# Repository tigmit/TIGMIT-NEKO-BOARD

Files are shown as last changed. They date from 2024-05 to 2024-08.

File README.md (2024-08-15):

# TIGMIT NEKO BOARD 

HEY fellow nerd :3
thanks for checking out my project hehe

This is a one man project trying to create (my) ultimate keyboard. taylored to the personal needs of a software developer with a thing for cute and weeby shit... hence the name :P 

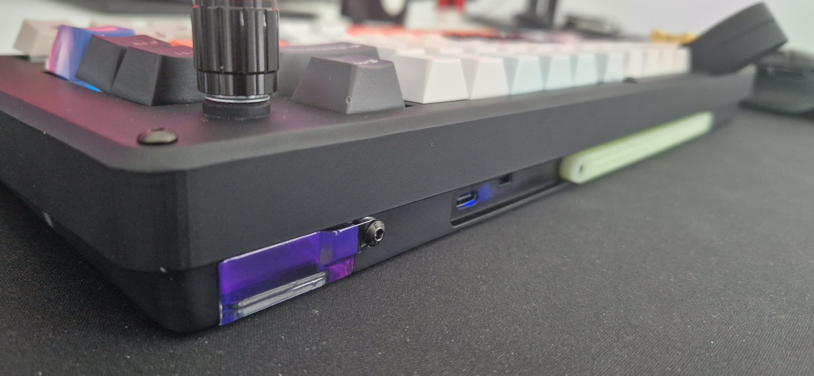
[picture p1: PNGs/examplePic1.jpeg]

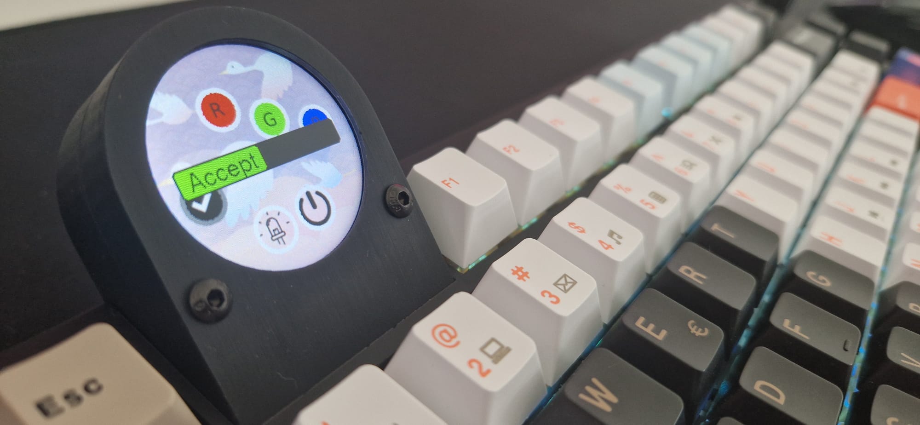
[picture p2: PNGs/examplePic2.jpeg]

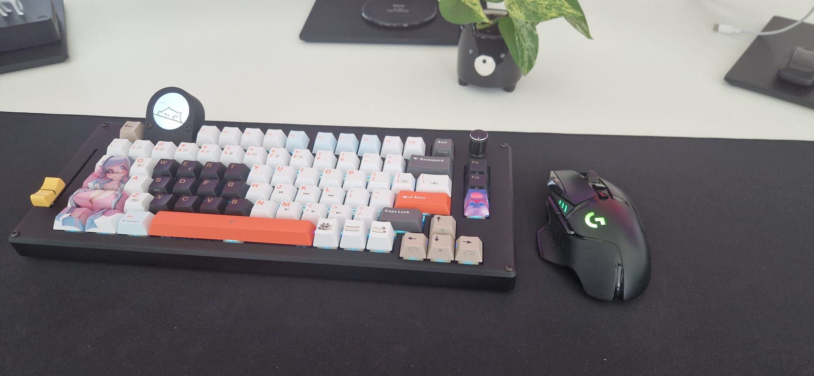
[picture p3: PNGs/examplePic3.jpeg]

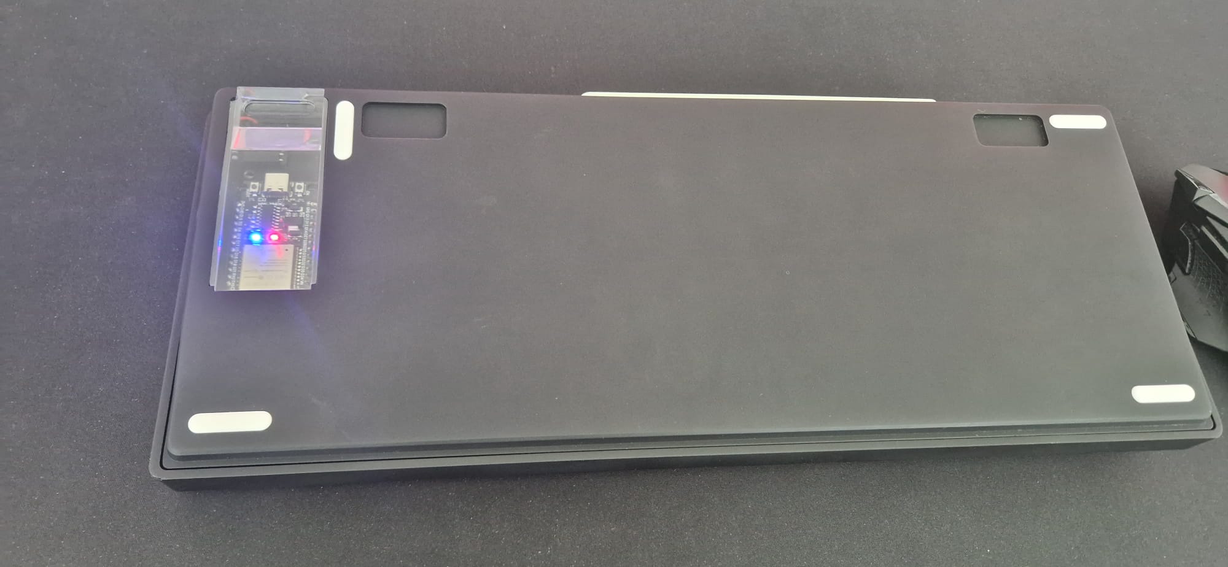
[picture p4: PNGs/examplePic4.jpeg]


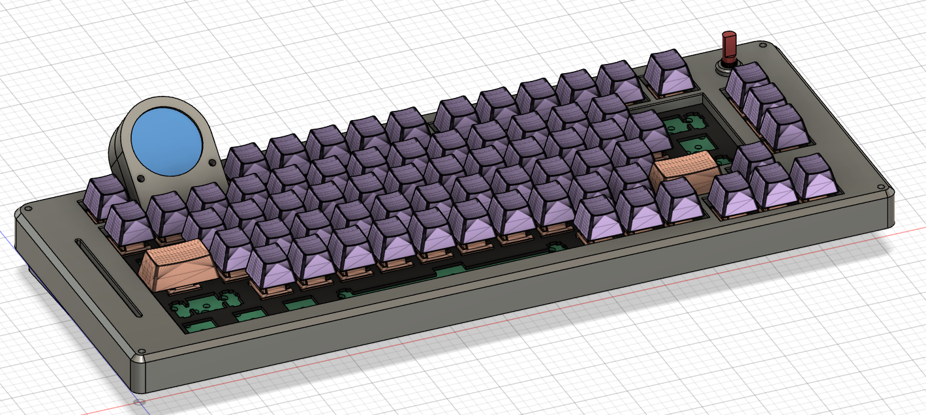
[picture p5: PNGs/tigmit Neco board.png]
TIGMIT NEKO BOARD


the project features 

- 79 keys in a kind of.. compact TKL arrangement.
- a 240 x 240 round Display
- rotary encoder
- analog slider
- fully controllable RGB for each key
- hot swappable switches
- fully custom Firmware (feel free to reuse for your project)
- wireless operation via Bluetooth
- a fully functioal shell with ato completion

to enable the NEKO SHELL go to debugSettings.hpp and enable ```#define DEVMODE ```
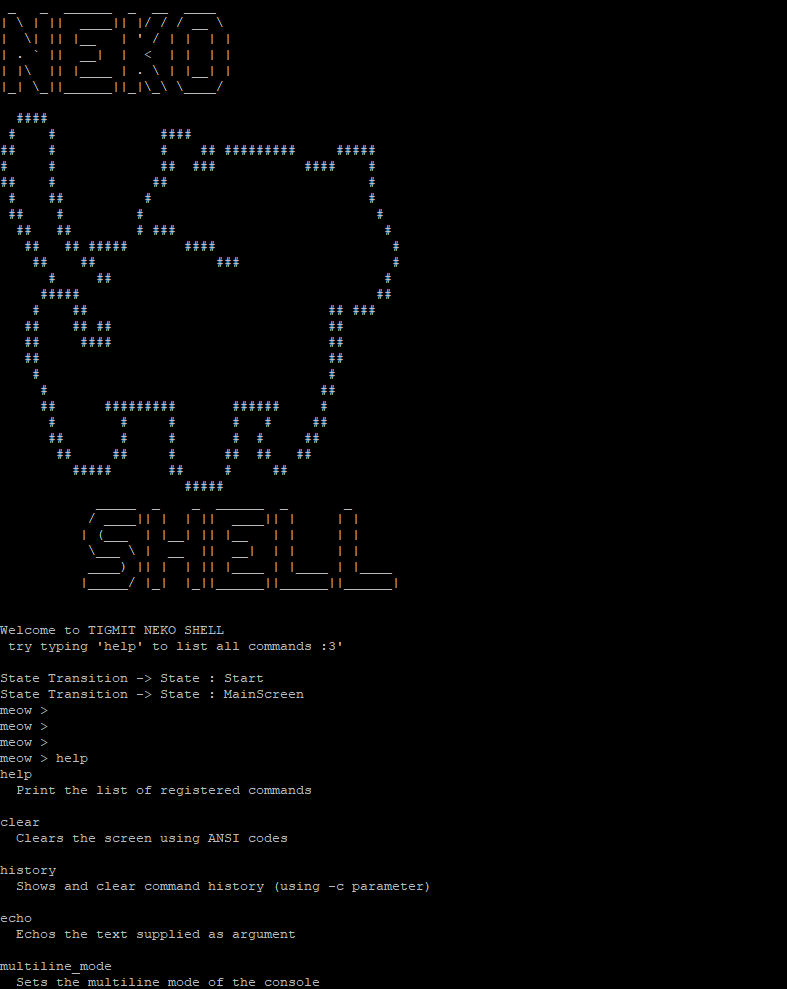
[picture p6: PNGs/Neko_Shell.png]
TIGMIT NEKO BOARD


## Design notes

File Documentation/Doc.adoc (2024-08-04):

# TIGMIT NEKO BOARD 

This is a one man project trying to create (my) ultimate keyboard. taylored to the personal needs of a software developer with a thing for cute and weeby shit... hence the name :P 

image::../PNGs/tigmit Neco board.png[]

the board features 

- 79 keys in a kind of.. compact TKL arrangement.
- a 240 x 240 round Display
- rotary encoder
- analog slider
- fully controllable RGB for each key
- hot swappable 
- the key-plate rests on foam pads to ensure a smoooth typing experience

it's a wireless board using bluetooth to connect to your devices :3

## The brain of the operation

is a esp32 vroom devkit. for now at least. perhaps i will change the controller at some point or integrate it onto the PCB.

anyways it can be accessed for programming via a lid in the bottom of the case as seen here:

image::../PNGs/tigmit Neco board back view.png[]
image::../PNGs/tigmit Neco board bottom view.png[]

it has a fixed angle between 4 and 5 degrees but supprts feet to change the angle to any requred needs really :3

to power the thing it uses a 8000mAh lipo battery with a breakout pcb that handles all of the power tasks like lipo protection and stepping up the battery voltage to 5V for the RGB LEDs

speaking of LEDs. the board has 79 adressable RGB LEDs. more specific SK6812MINI-E (datasheet in Documents/miscFiles Folder)

## KEY Matrix

the keys are arranged as a 6 x 15 Keymatrix. but wait. that uses a total of 21 I/O PINS?! how can we still controll a Display, a slider, and a Rotary encoder with pins to spare?????? well simple hehe the board has TWO 8 bit shift registers wich are controlled via SPI for maximum speeeed. gotta go fast kid.

image::../PNGs/shift registers.png[]

this way its possible to save a massive ammount of pins. reducing the total ammount needed from 21 to basicllay just 8 pins for the whole keymatrix :P 

NOTE: its still very possible to reach a nice 1kHz polling rate for each key so there is no noticable lag when typing because we are utalizing SPI to controll the Shift registers :3

BUT! another trick is needed to pull all of this off with just one ESP32...

### Multicore processing

the esp32 features a delicios dual core MCU which we can use to our advantage hehe

Core 0 runs ONLY the key matrix polling and has priority over all the other tasks. to make absolutely sure that the keyboard... well... TYPES!

Core 1 handles all the other tasks like refreshing the display and running the Display Statemachine with alongside RGB tasks and sooo on. at the expense of a slightly slower refresh rate of the display. but its still fast enough for a nice experience :3 and the display has a buffer itself which eliminates the need to refresh it constantly all together ;P so we only need to update it in when we have to

# USING GC9A01 round TFT Display:

## setup:

### TFT_eSPI Lib

to use the GC9A01 Display, i am using the TFT_eSPI Lib by Bodmer'
https://github.com/Bodmer/TFT_eSPI
it requires some work to set it up for our particular Display.
thats why the TFT_eSPI was moved to the local libs folder in order to make it easyer to clone the repo.

if it does get lost then following changes need to be made in lib\TFT_eSPI\User_Setup.h:

 - select the right Driver. In Line 69 LOL ROFL (/* _ *)/  use #define GC9A01_DRIVER

 - set the requred Pin defines for the Display:

 - you can simply delete everything in the user_setup file and replace it with this setup:

[source,c++]
----
    #define USER_SETUP_INFO "User_Setup"
    #define DISABLE_ALL_LIBRARY_WARNINGS
    #define GC9A01_DRIVER

    #define TFT_MOSI 4  // SDA data signal          (Usr defined)
    #define TFT_SCLK 18 // Clock signal             (must be SCK on your board)
    #define TFT_CS 15   // Chip select control pin  (Usr defined)
    #define TFT_DC 2    // Data Command control pin (Usr defined)
    #define TFT_RST 5   // Reset pin                (Usr defined)

    // Comment out the #defines below with // to stop that font being loaded
    // The ESP8366 and ESP32 have plenty of memory so commenting out fonts is not
    // normally necessary. If all fonts are loaded the extra FLASH space required is
    // about 17Kbytes. To save FLASH space only enable the fonts you need!
    
    #define LOAD_GLCD // Font 1. Original Adafruit 8 pixel font needs ~1820 bytes in
                      // FLASH
    #define LOAD_FONT2 // Font 2. Small 16 pixel high font, needs ~3534 bytes in
                       // FLASH, 96 characters
    #define LOAD_FONT4 // Font 4. Medium 26 pixel high font, needs ~5848 bytes in
                       // FLASH, 96 characters
    #define LOAD_FONT6 // Font 6. Large 48 pixel font, needs ~2666 bytes in FLASH,
                       // only characters 1234567890:-.apm
    #define LOAD_FONT7 // Font 7. 7 segment 48 pixel font, needs ~2438 bytes in
                       // FLASH, only characters 1234567890:-.
    #define LOAD_FONT8 // Font 8. Large 75 pixel font needs ~3256 bytes in FLASH,
                       // only characters 1234567890:-.
    //#define LOAD_FONT8N // Font 8. Alternative to Font 8 above, slightly narrower,
    // so 3 digits fit a 160 pixel TFT
    #define LOAD_GFXFF // FreeFonts. Include access to the 48 Adafruit_GFX free
                       // fonts FF1 to FF48 and custom fonts
    
    // Comment out the #define below to stop the SPIFFS filing system and smooth
    // font code being loaded this will save ~20kbytes of FLASH
    #define SMOOTH_FONT
    
    // #define SPI_FREQUENCY   1000000
    // #define SPI_FREQUENCY   5000000
    // #define SPI_FREQUENCY  10000000
    // #define SPI_FREQUENCY  20000000
    #define SPI_FREQUENCY 27000000
    // #define SPI_FREQUENCY  40000000
    // #define SPI_FREQUENCY  55000000 // STM32 SPI1 only (SPI2 maximum is 27MHz)
    // #define SPI_FREQUENCY  80000000
    
    // Optional reduced SPI frequency for reading TFT
    #define SPI_READ_FREQUENCY 20000000
    
    // The XPT2046 requires a lower SPI clock rate of 2.5MHz so we define that here:
    #define SPI_TOUCH_FREQUENCY 2500000
----

connect these pins as per the defines and you should be good to go.

# NEKO SHELL

The project features a fully functional live console/Shell to debug and play around.

find more info on how to create your own commands inside ```NekoShell.hpp```

To enable the NEKO SHELL go to debugSettings.hpp and enable ```#define DEVMODE```



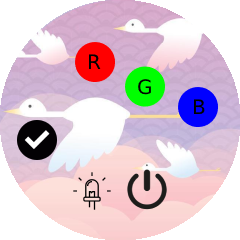
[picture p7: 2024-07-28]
PNGs/DSPwallpapers/LED_Settings_Screen.png

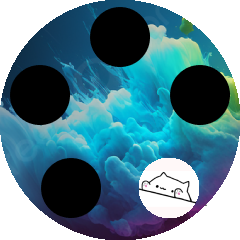
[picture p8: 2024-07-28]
PNGs/DSPwallpapers/main_menu_screen1.png

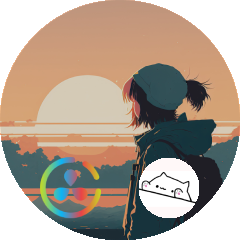
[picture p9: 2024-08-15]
PNGs/DSPwallpapers/main_menu_screen.png

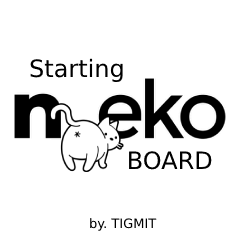
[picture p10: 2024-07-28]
PNGs/DSPwallpapers/start screen with name.png

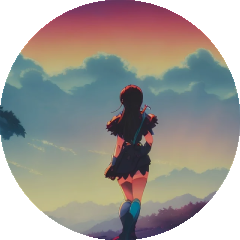
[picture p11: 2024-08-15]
PNGs/DSPwallpapers/idleScreen.png

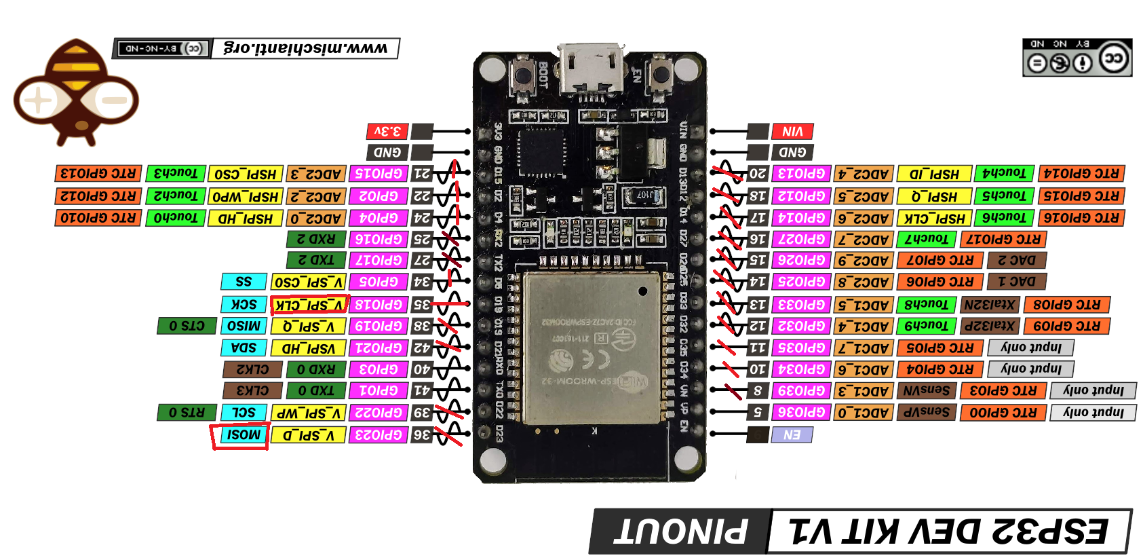
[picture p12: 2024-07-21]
Documentation/miscFiles/ESP32-DOIT-DEV-KIT-v1-pinout-mischianti.png

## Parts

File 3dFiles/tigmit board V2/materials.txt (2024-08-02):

bottom main case:
SLA Resin -> imagine black

display front plate:
SLA Resin -> imagine black

Display mount block:
SLA Resin -> imagine black

Lid Main case:
SLA Resin -> imagine black

MCU access lid:
SLA Resin -> 8001 Resin transparent

Keyplate:
SLA Resin -> 8001 Resin Translucent

beauty rail:
SLA Resin -> X Resin

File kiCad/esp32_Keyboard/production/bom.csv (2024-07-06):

Designator | Footprint | Quantity | Value | LCSC Part #
C1, C2 | CP_Elec_6.3x5.2 | 2 | 100µF
D1, D10, D11, D12, D13, D14, D15, D16, D17, D18, D19, D2, D20, D21, D22, D23, D24, D25, D26, D27, D28, D29, D3, D30, D31, D32, D33, D34, D35, D36, D37, D38, D39, D4, D40, D41, D42, D43, D44, D45, D46, D47, D48, D49, D5, D50, D51, D52, D53, D54, D55, D56, D57, D58, D59, D6, D60, D61, D62, D63, D64, D65, D66, D67, D68, D69, D7, D70, D71, D72, D73, D74, D75, D76, D77, D78, D79, D8, D9 | Diode_SOD-123 | 79 | Diode
Dsp1 | PinHeader_1x07_P2.54mm_Vertical | 1 | ~
PWR_Module1 | PinHeader_1x04_P2.54mm_Vertical | 1 | Conn_01x04_Pin
R1, R2, R3, R4, R5, R6, R7 | R_Axial_DIN0204_L3.6mm_D1.6mm_P7.62mm_Horizontal | 7 | 10k
RotaryEnc1 | PinHeader_1x05_P2.54mm_Vertical | 1 | Conn_01x05_Pin
S1, S2, S3 | STAB_MX_2u | 3 | stab 2u
S4 | STAB_MX_6.25u | 1 | stab space 6.25u
SW1, SW10, SW11, SW12, SW13, SW14, SW15, SW16, SW17, SW18, SW19, SW2, SW20, SW21, SW22, SW23, SW24, SW25, SW26, SW27, SW28, SW29, SW3, SW30, SW31, SW32, SW33, SW34, SW35, SW36, SW37, SW38, SW39, SW4, SW40, SW41, SW42, SW43, SW44, SW45, SW46, SW47, SW48, SW49, SW5, SW50, SW51, SW52, SW53, SW54, SW55, SW56, SW57, SW58, SW59, SW6, SW60, SW61, SW62, SW63, SW64, SW65, SW66, SW67, SW68, SW69, SW7, SW70, SW71, SW72, SW73, SW74, SW75, SW76, SW77, SW78, SW79, SW8, SW9 | hotswap socket with neopixel | 79 | ~
U1 | SNH Shift register | 1 | SN74HC595NG4 FirstShift
U2 | SNH Shift register | 1 | SN74HC595NG4 SecondShift
U3 | CONV_BOB-12009 | 1 | BOB-12009
U4 | b103 multichannel fader pot | 1 | ~
U5 | ESP32 Vroom Devkit V1 | 1 | ESP32-DEVKIT-V1 Matrix Handler

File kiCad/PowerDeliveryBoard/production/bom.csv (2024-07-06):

Designator | Footprint | Quantity | Value | LCSC Part #
BT1 | battery solder pins | 1 | Battery_Cell
C1 | CP_Elec_6.3x5.2 | 1 | 100µF
DCDC1 | DCDC-Converter | 1 | ~
J1 | PinHeader_1x04_P2.54mm_Vertical | 1 | Conn_01x04_Pin
R1 | R_Axial_DIN0204_L3.6mm_D1.6mm_P7.62mm_Horizontal | 1 | 4k7
R2 | R_Axial_DIN0204_L3.6mm_D1.6mm_P7.62mm_Horizontal | 1 | 10k
R3, R4 | R_Axial_DIN0204_L3.6mm_D1.6mm_P7.62mm_Horizontal | 2 | 100k
U1 | TP4056-18650 | 1 | ~
U2 | SK12D07VG4 | 1 | SK12D07VG4

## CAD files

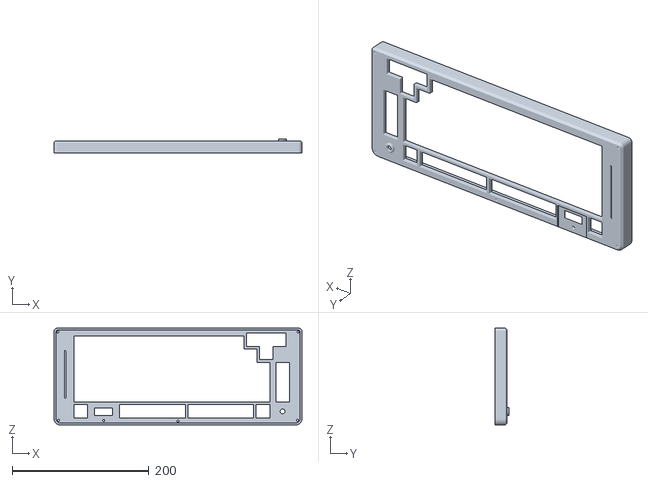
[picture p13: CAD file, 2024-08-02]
3dFiles/tigmit board V2/Lid Main case.stl
362.9 x 21.1 x 141.8

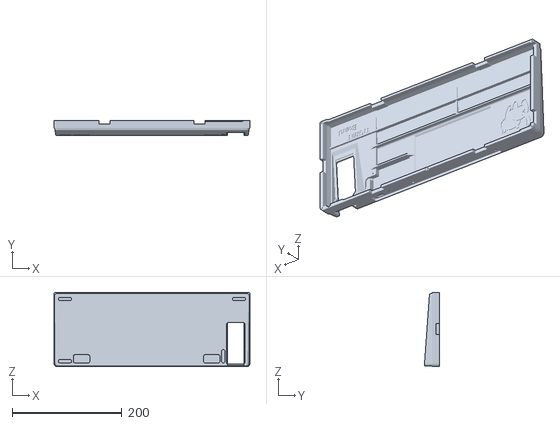
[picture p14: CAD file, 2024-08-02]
3dFiles/tigmit board V2/bottom Main case.stl
356.5 x 27.9 x 135.4

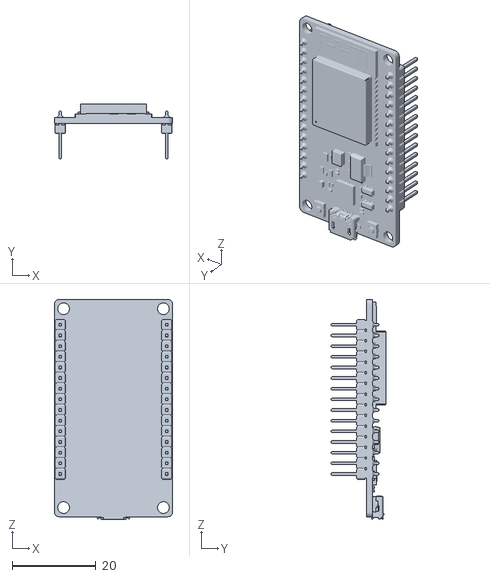
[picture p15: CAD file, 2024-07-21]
3dFiles/ESP32-DEVKIT-V1--3DModel.stl
28.2 x 13.1 x 52.4

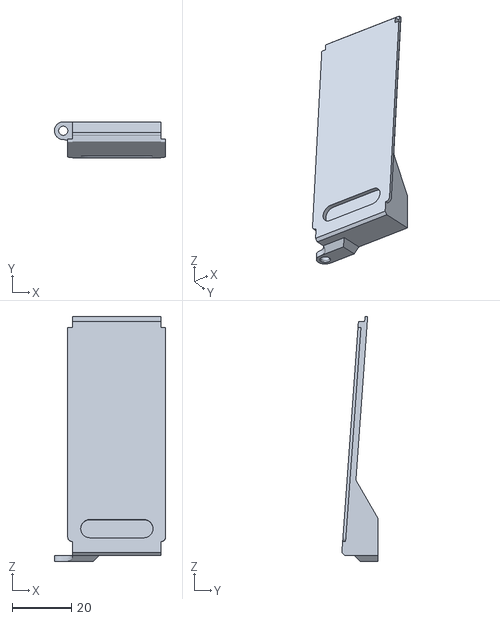
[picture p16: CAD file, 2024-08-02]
3dFiles/tigmit board V2/MCU access Lid_.stl
37.5 x 12.2 x 82.6

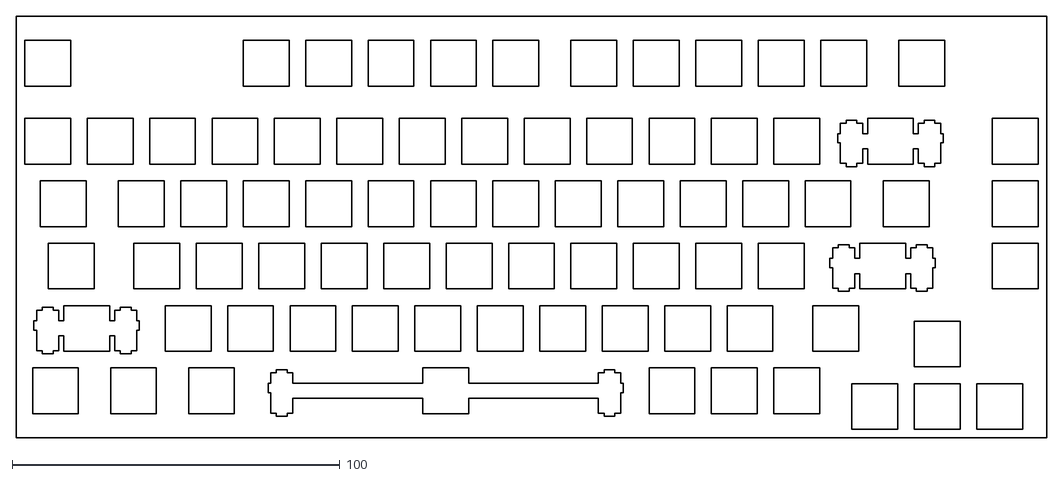
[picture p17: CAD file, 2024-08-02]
Documentation/miscFiles/TKL_Cherry_Only_Keyplate.dxf
314.3 x 128.6

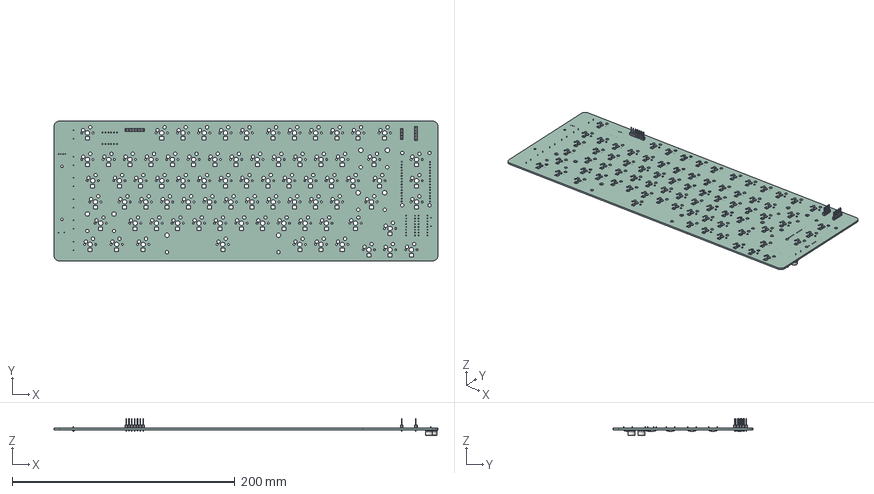
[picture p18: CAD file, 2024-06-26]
kiCad/esp32_Keyboard/esp32_Keyboard.step
344.5 x 125.4 x 15.4 mm
PinHeader_1x05_P254mm_Vertical
PinHeader_1x04_P254mm_Vertical
PinHeader_1x07_P254mm_Vertical
CP_Elec_63x52 x 2
R_Axial_DIN0204_L36mm_D16mm_P762mm_Horizontal x 7
_autosave-esp32_Keyboard_PCB

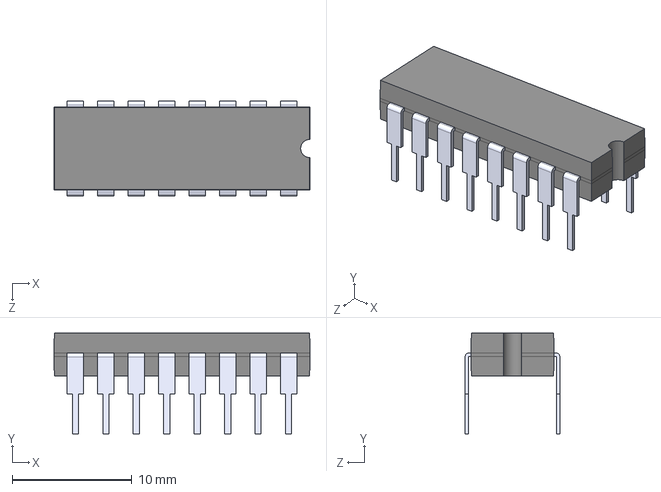
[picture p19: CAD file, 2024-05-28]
kiCad/parts/SN74HC595NG4/SN74HC595NG4.step
21.3 x 8.38 x 7.90 mm

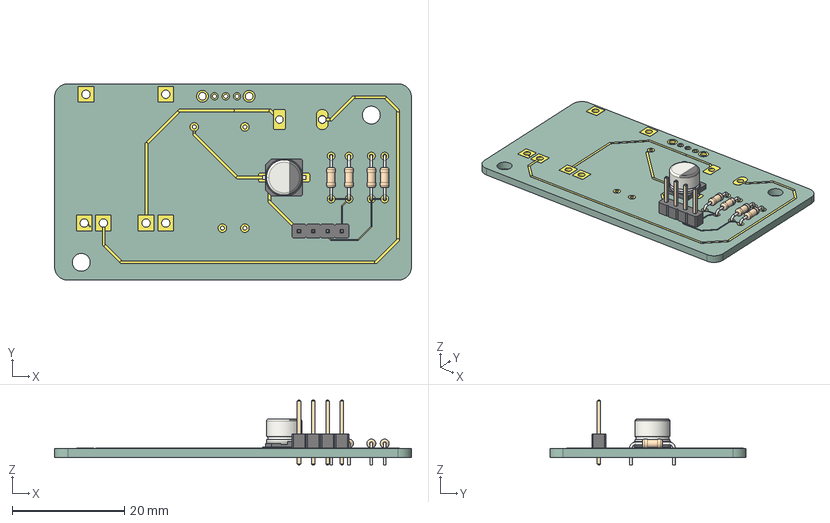
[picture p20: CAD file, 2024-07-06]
kiCad/PowerDeliveryBoard/PowerDeliveryBoard.step
63.5 x 34.9 x 11.5 mm
R_Axial_DIN0204_L36mm_D16mm_P762mm_Horizontal x 4
PinHeader_1x04_P254mm_Vertical
CP_Elec_63x52
PowerDeliveryBoard_track_1
PowerDeliveryBoard_track_2
PowerDeliveryBoard_track_3
PowerDeliveryBoard_track_4
PowerDeliveryBoard_track_5
PowerDeliveryBoard_track_6
PowerDeliveryBoard_track_7
PowerDeliveryBoard_track_8
PowerDeliveryBoard_track_9
PowerDeliveryBoard_track_10
PowerDeliveryBoard_track_11
PowerDeliveryBoard_track_12
PowerDeliveryBoard_track_13
PowerDeliveryBoard_track_14
PowerDeliveryBoard_track_15
PowerDeliveryBoard_track_16
PowerDeliveryBoard_track_17
PowerDeliveryBoard_track_18
PowerDeliveryBoard_track_19
PowerDeliveryBoard_track_20
PowerDeliveryBoard_track_21
PowerDeliveryBoard_track_22
PowerDeliveryBoard_track_23
PowerDeliveryBoard_track_24
PowerDeliveryBoard_track_25
PowerDeliveryBoard_track_26
PowerDeliveryBoard_track_27
PowerDeliveryBoard_track_28
PowerDeliveryBoard_track_29
PowerDeliveryBoard_track_30
PowerDeliveryBoard_track_31
PowerDeliveryBoard_track_32
PowerDeliveryBoard_track_33
PowerDeliveryBoard_track_34
PowerDeliveryBoard_track_35
PowerDeliveryBoard_track_36
PowerDeliveryBoard_track_37
PowerDeliveryBoard_track_38
PowerDeliveryBoard_track_39
PowerDeliveryBoard_track_40
PowerDeliveryBoard_track_41
PowerDeliveryBoard_track_42
PowerDeliveryBoard_track_43
PowerDeliveryBoard_track_44
PowerDeliveryBoard_track_45
PowerDeliveryBoard_track_46
PowerDeliveryBoard_track_47
PowerDeliveryBoard_track_48
PowerDeliveryBoard_track_49
PowerDeliveryBoard_track_50
PowerDeliveryBoard_pad_1
PowerDeliveryBoard_pad_2
PowerDeliveryBoard_pad_3
PowerDeliveryBoard_pad_4
PowerDeliveryBoard_pad_5
PowerDeliveryBoard_pad_6
PowerDeliveryBoard_pad_7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

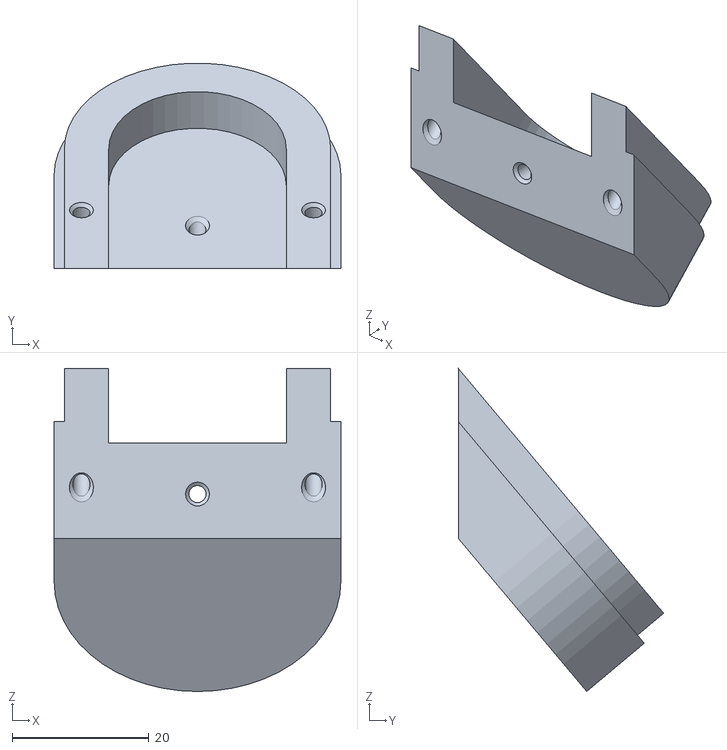
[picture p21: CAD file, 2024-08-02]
3dFiles/tigmit board V2/Display mount block.stl
42.0 x 30.1 x 47.3

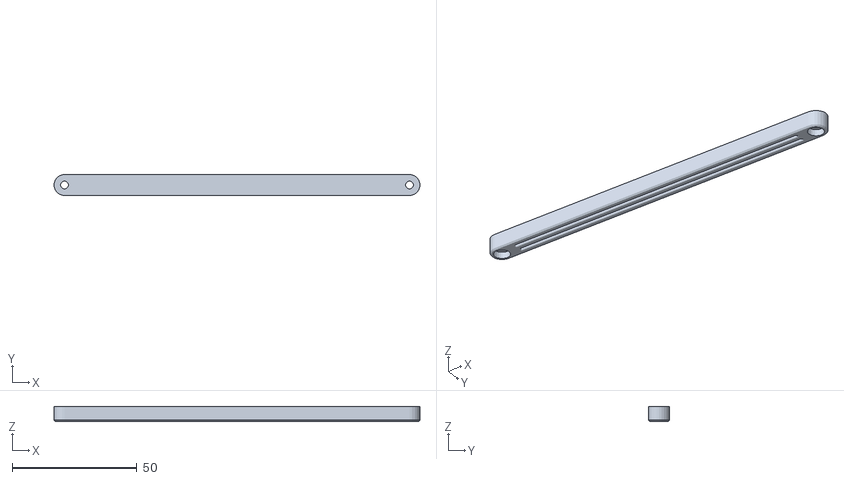
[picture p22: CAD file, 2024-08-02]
3dFiles/tigmit board V2/beauty rail.stl
146.5 x 8.40 x 6.00

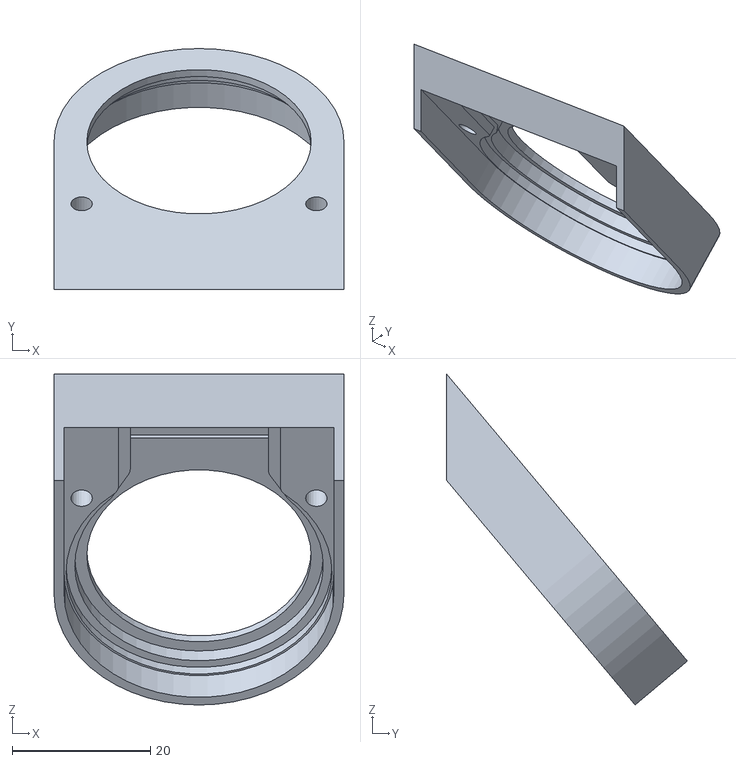
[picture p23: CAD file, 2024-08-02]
3dFiles/tigmit board V2/display front Plate.stl
42.0 x 34.9 x 47.9

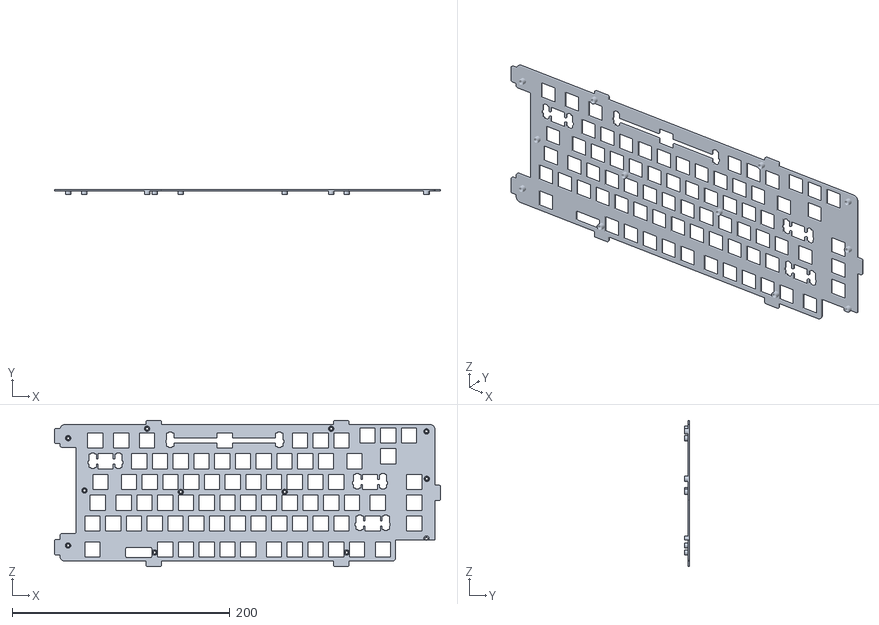
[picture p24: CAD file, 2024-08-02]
3dFiles/tigmit board V2/keyplate MX only pcb mount stabs.stl
354.5 x 5.00 x 134.1

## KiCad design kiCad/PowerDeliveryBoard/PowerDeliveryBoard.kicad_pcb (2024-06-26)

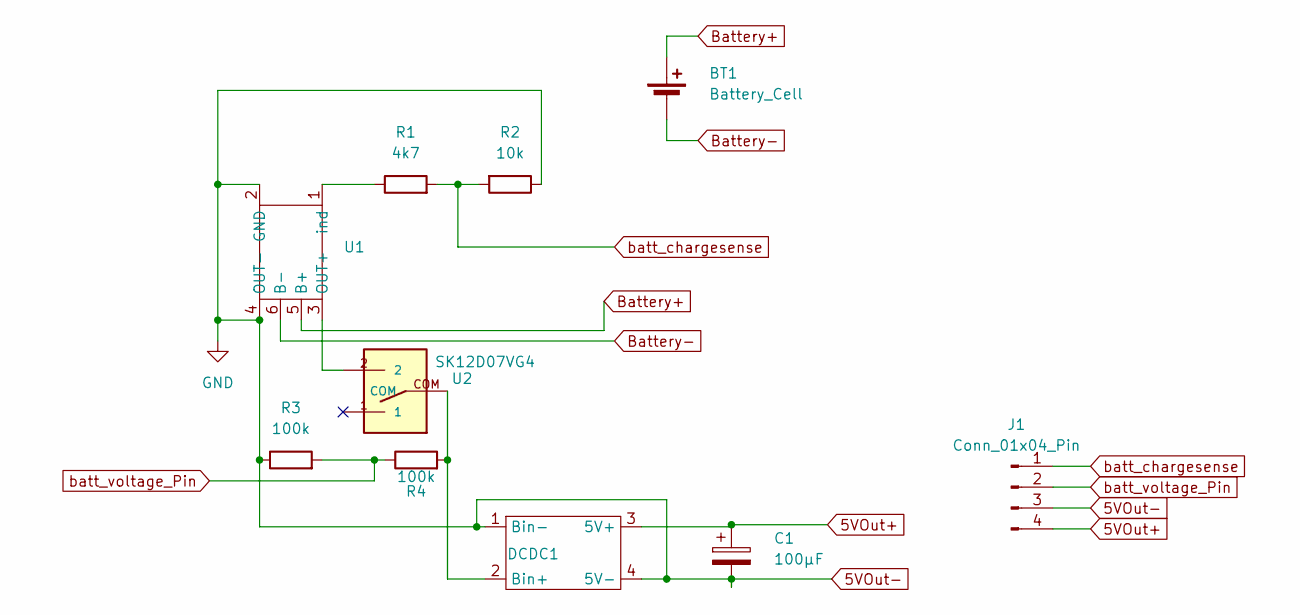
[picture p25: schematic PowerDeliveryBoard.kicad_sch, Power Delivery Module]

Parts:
BT1: Battery_Cell; battery solder pins
C1: 100µF; CP_Elec_6.3x5.2
DCDC1: DCDC-Converter
J1: Conn_01x04_Pin; PinHeader_1x04_P2.54mm_Vertical
R1: 4k7; R_Axial_DIN0204_L3.6mm_D1.6mm_P7.62mm_Horizontal
R2: 10k; R_Axial_DIN0204_L3.6mm_D1.6mm_P7.62mm_Horizontal
R3, R4: 100k; R_Axial_DIN0204_L3.6mm_D1.6mm_P7.62mm_Horizontal
U1: TP4056-18650
U2: SK12D07VG4

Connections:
5VOut+: C1.1, DCDC1.3 (5V+), J1.4
5VOut-: C1.2, DCDC1.1 (Bin-), DCDC1.4 (5V-), J1.3, R2.1, R3.1, U1.2 (GND), U1.4 (OUT-)
Battery+: BT1.1 (+), U1.5 (B+)
Battery-: BT1.2 (-), U1.6 (B-)
unnamed: DCDC1.2 (Bin+), R4.2, U2.COM
unnamed: U1.3 (OUT+), U2.2
unnamed: R1.1, U1.1 (ind)
batt_chargesense: J1.1, R1.2, R2.2
batt_voltage_Pin: J1.2, R3.2, R4.1

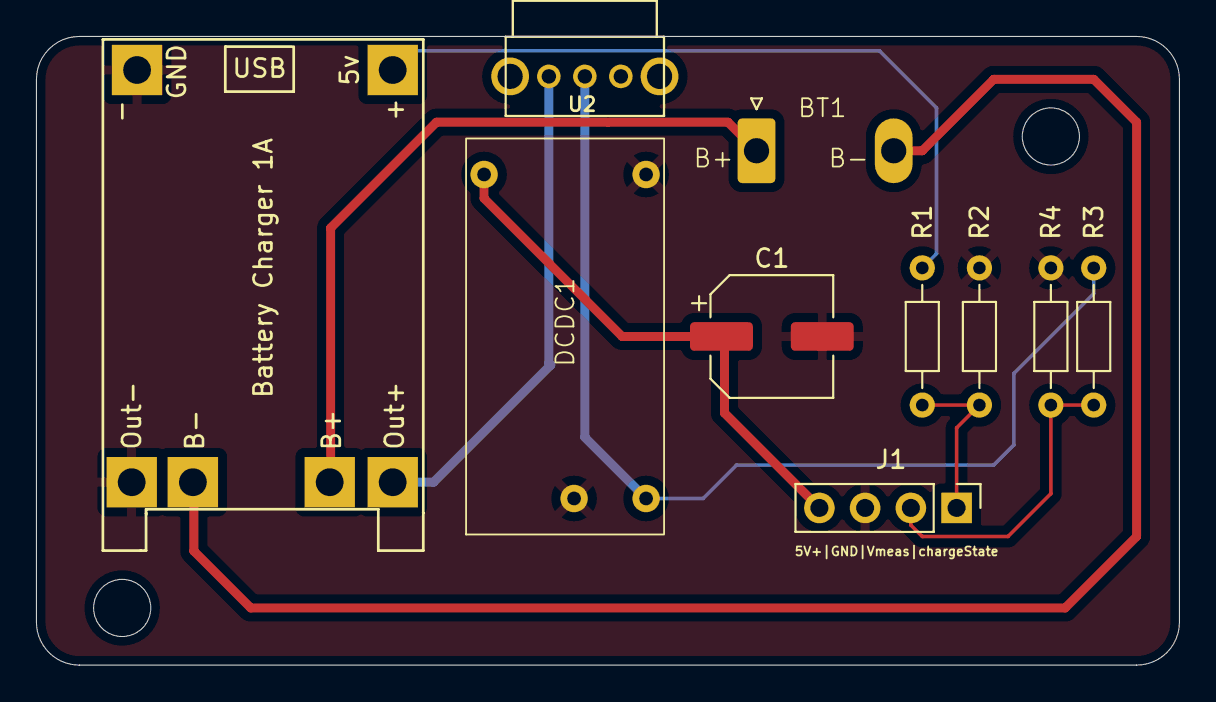
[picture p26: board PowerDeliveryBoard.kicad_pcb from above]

Board: 2 copper layers, 63.5 x 34.9 mm, 10 parts (0 on the bottom side), 9 nets.

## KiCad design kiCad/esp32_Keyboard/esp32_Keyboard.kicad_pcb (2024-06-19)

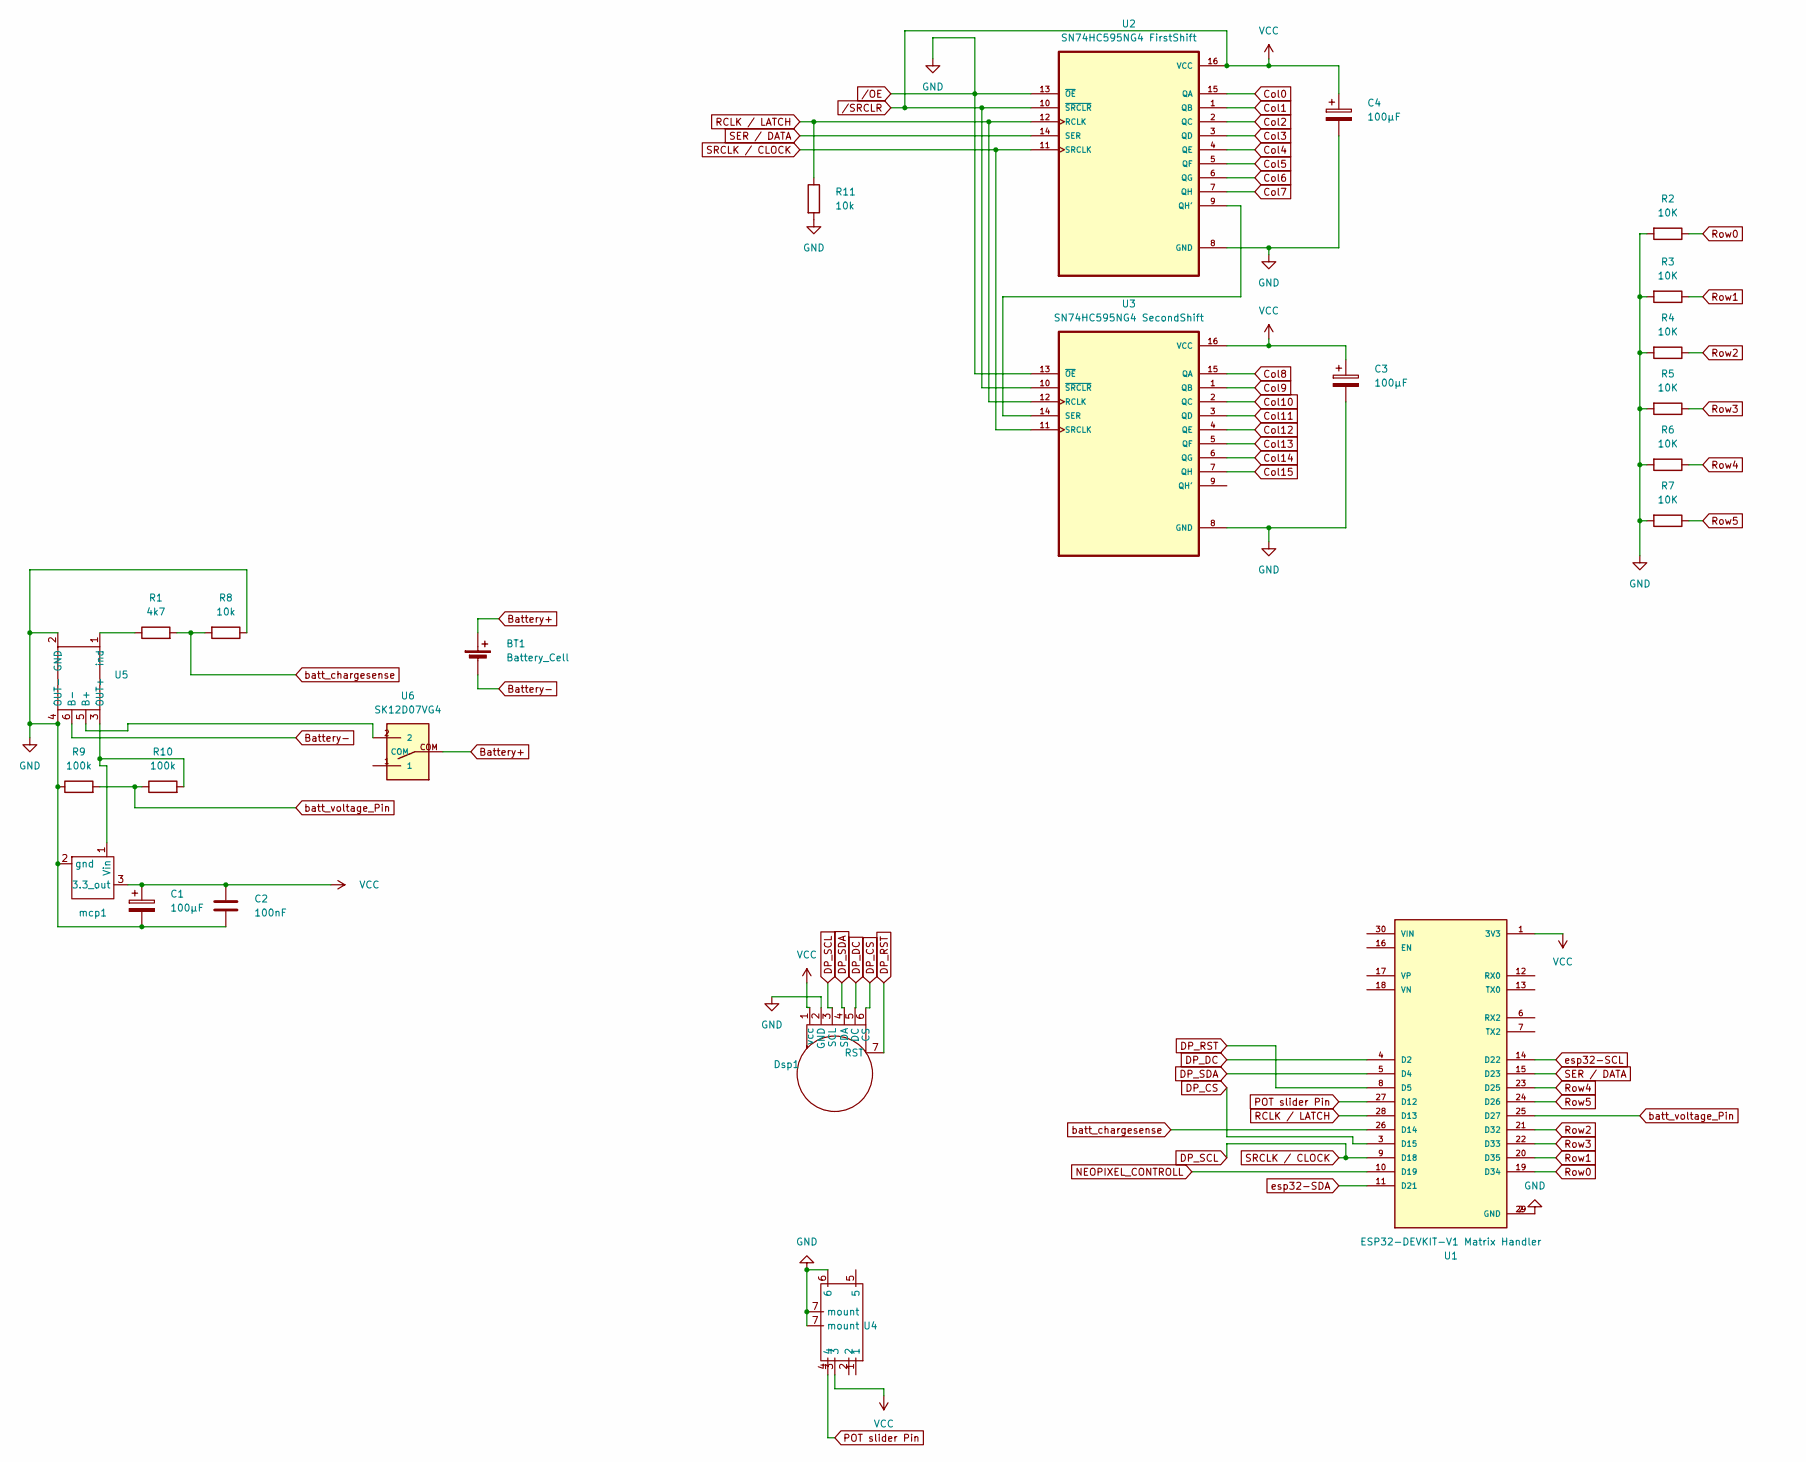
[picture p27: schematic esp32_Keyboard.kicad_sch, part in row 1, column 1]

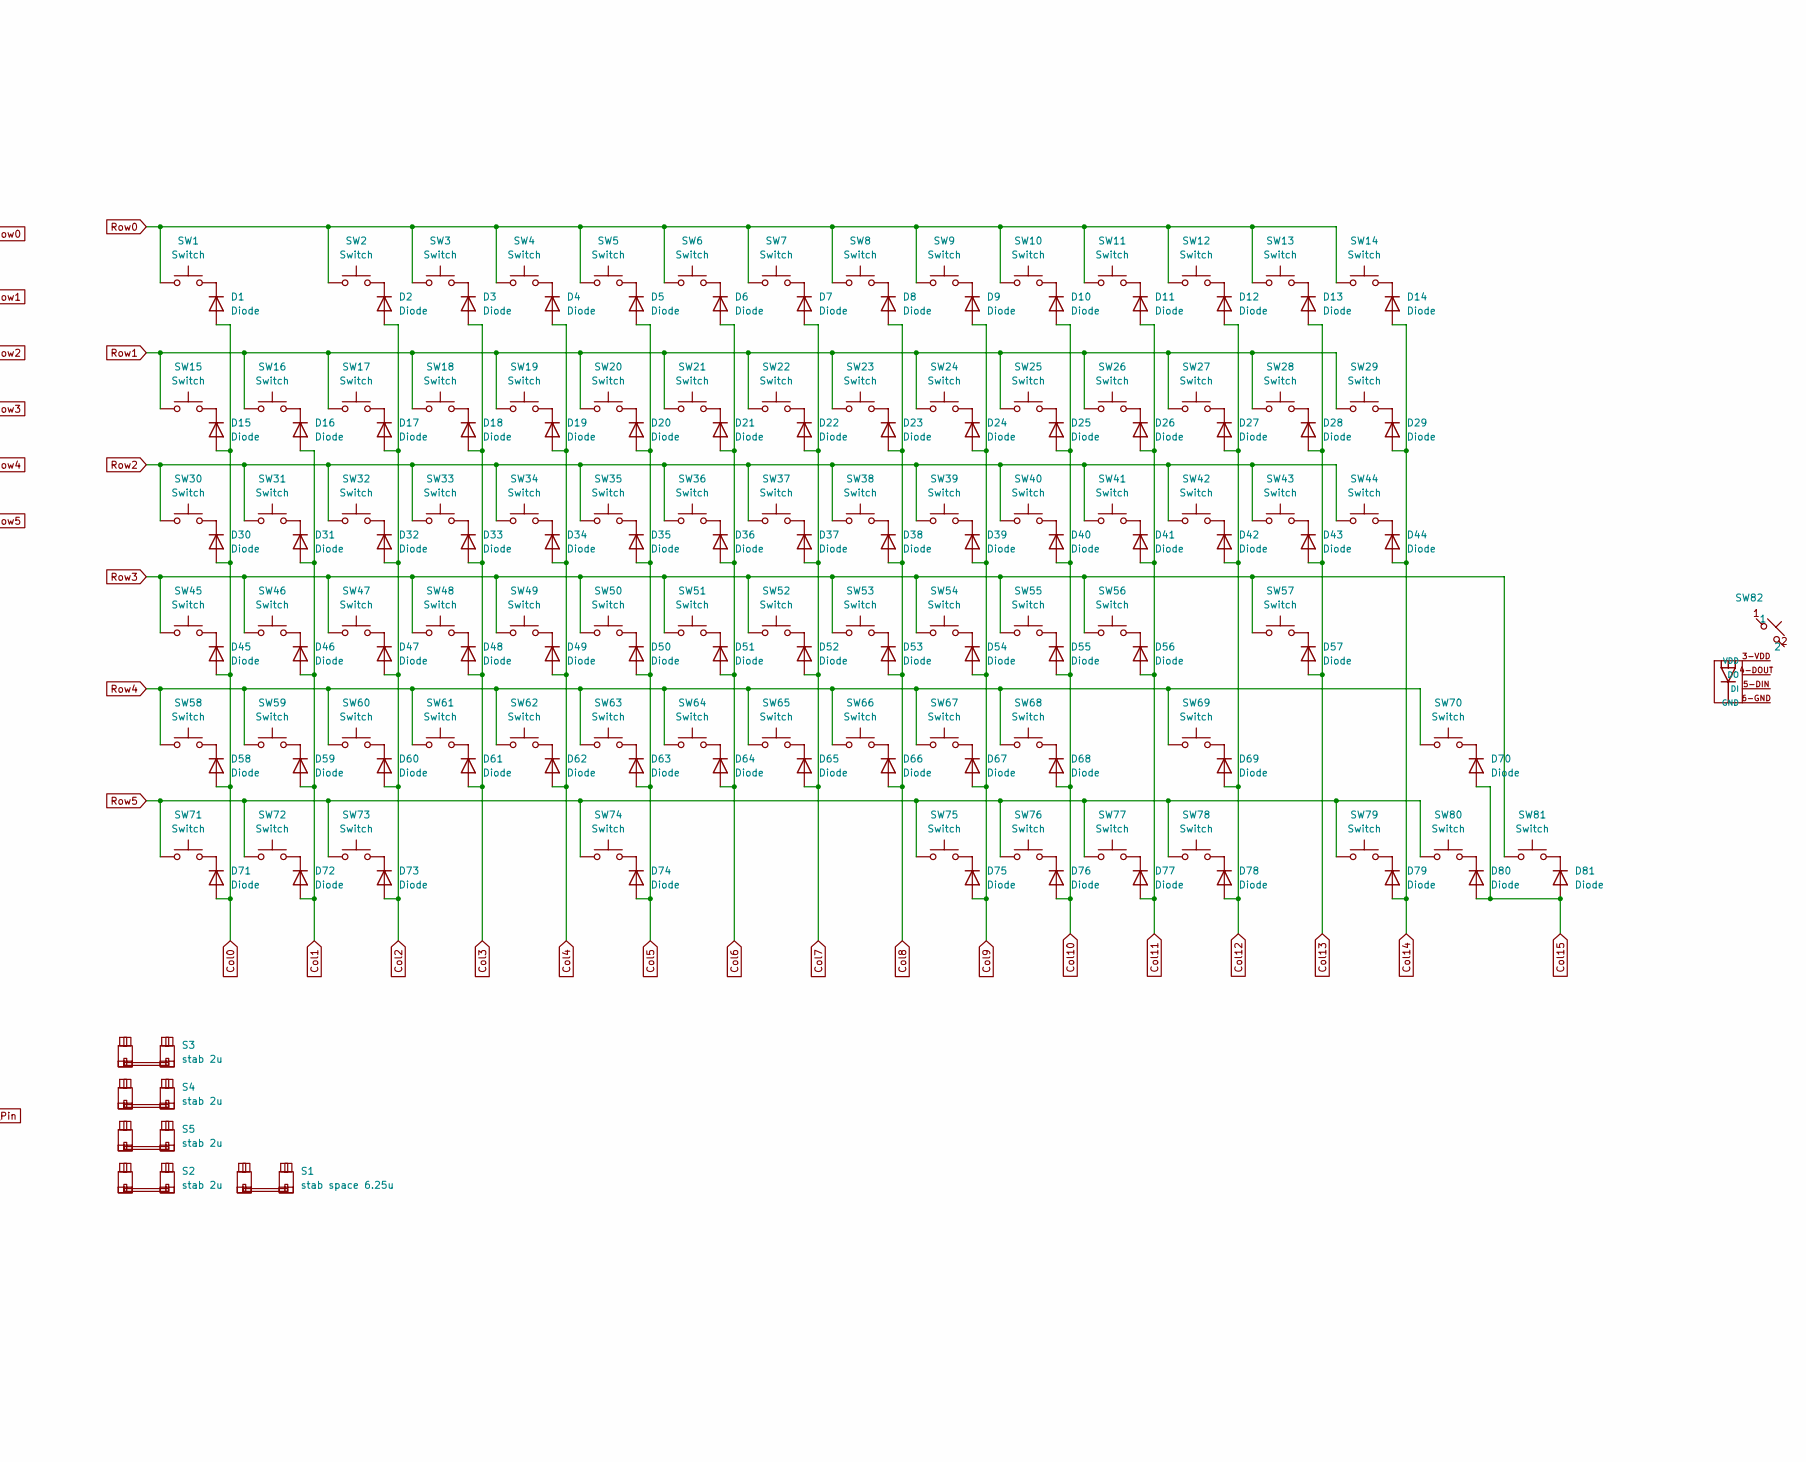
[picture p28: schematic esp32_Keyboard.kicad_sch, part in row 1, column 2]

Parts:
BT1: Battery_Cell; battery solder pins
C1, C3, C4: 100µF; CP_Radial_D10.0mm_P2.50mm
C2: 100nF; C_Rect_L7.0mm_W2.5mm_P5.00mm
D1, D2, D3, D4, D5, D6, D7, D8, D9, D10, D11, D12, D13, D14, D15, D16, D17, D18, D19, D20, D21, D22, D23, D24, D25, D26, D27, D28, D29, D30, D31, D32, D33, D34, D35, D36, D37, D38, D39, D40, D41, D42, D43, D44, D45, D46, D47, D48, D49, D50, D51, D52, D53, D54, D55, D56, D57, D58, D59, D60, D61, D62, D63, D64, D65, D66, D67, D68, D69, D70, D71, D72, D73, D74, D75, D76, D77, D78, D79, D80, D81: Diode; Diode_SOD-123
Dsp1: PinHeader_1x07_P2.54mm_Vertical
R1: 4k7; R_Axial_DIN0204_L3.6mm_D1.6mm_P7.62mm_Horizontal
R2, R3, R4, R5, R6, R7: 10K; R_Axial_DIN0204_L3.6mm_D1.6mm_P7.62mm_Horizontal
R8, R11: 10k; R_Axial_DIN0204_L3.6mm_D1.6mm_P7.62mm_Horizontal
R9, R10: 100k; R_Axial_DIN0204_L3.6mm_D1.6mm_P7.62mm_Horizontal
S1: stab space 6.25u; STAB_MX_6.25u
S2, S3, S4, S5: stab 2u; STAB_MX_2u
SW1, SW2, SW3, SW4, SW5, SW6, SW7, SW8, SW9, SW10, SW11, SW12, SW13, SW14, SW15, SW16, SW17, SW18, SW19, SW20, SW21, SW22, SW23, SW24, SW25, SW26, SW27, SW29, SW31, SW32, SW33, SW34, SW35, SW36, SW37, SW38, SW39, SW40, SW41, SW42, SW44, SW46, SW47, SW48, SW49, SW50, SW51, SW52, SW53, SW54, SW55, SW56, SW59, SW60, SW61, SW62, SW63, SW64, SW65, SW66, SW67, SW68, SW70, SW79, SW80, SW81: Switch; Hotswap_MX_1.00u
SW28: Switch; Hotswap_MX_2.00u
SW30, SW43: Switch; Hotswap_MX_1.50u
SW45: Switch; Hotswap_MX_1.75u
SW57, SW58: Switch; Hotswap_MX_2.25u
SW69: Switch; Hotswap_MX_2.75u
SW71, SW72, SW73, SW75, SW76, SW77, SW78: Switch; Hotswap_MX_1.25u
SW74: Switch; Hotswap_MX_6.25u
SW82: hotswap socket with neopixel
U1: ESP32-DEVKIT-V1 Matrix Handler; ESP32 Vroom Devkit V1; PARTREV N/A
U2: SN74HC595NG4 FirstShift; SNH Shift register
U3: SN74HC595NG4 SecondShift; SNH Shift register
U4: b103 multichannel fader pot
U5: TP4056-18650
U6: SK12D07VG4
mcp1: MCP1700 3.3V

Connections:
Battery+: BT1.1 (+), U6.COM
Battery-: BT1.2 (-), U5.6 (B-)
Col0: D1.2 (A), D15.2 (A), D30.2 (A), D45.2 (A), D58.2 (A), D71.2 (A), U2.15 (QA)
Col1: D16.2 (A), D31.2 (A), D46.2 (A), D59.2 (A), D72.2 (A), U2.1 (QB)
Col2: D2.2 (A), D17.2 (A), D32.2 (A), D47.2 (A), D60.2 (A), D73.2 (A), U2.2 (QC)
Col3: D3.2 (A), D18.2 (A), D33.2 (A), D48.2 (A), D61.2 (A), U2.3 (QD)
Col4: D4.2 (A), D19.2 (A), D34.2 (A), D49.2 (A), D62.2 (A), U2.4 (QE)
Col5: D5.2 (A), D20.2 (A), D35.2 (A), D50.2 (A), D63.2 (A), D74.2 (A), U2.5 (QF)
Col6: D6.2 (A), D21.2 (A), D36.2 (A), D51.2 (A), D64.2 (A), U2.6 (QG)
Col7: D7.2 (A), D22.2 (A), D37.2 (A), D52.2 (A), D65.2 (A), U2.7 (QH)
Col8: D8.2 (A), D23.2 (A), D38.2 (A), D53.2 (A), D66.2 (A), U3.15 (QA)
Col9: D9.2 (A), D24.2 (A), D39.2 (A), D54.2 (A), D67.2 (A), D75.2 (A), U3.1 (QB)
Col10: D10.2 (A), D25.2 (A), D40.2 (A), D55.2 (A), D68.2 (A), D76.2 (A), U3.2 (QC)
Col11: D11.2 (A), D26.2 (A), D41.2 (A), D56.2 (A), D77.2 (A), U3.3 (QD)
Col12: D12.2 (A), D27.2 (A), D42.2 (A), D69.2 (A), D78.2 (A), U3.4 (QE)
Col13: D13.2 (A), D28.2 (A), D43.2 (A), D57.2 (A), U3.5 (QF)
Col14: D14.2 (A), D29.2 (A), D44.2 (A), D79.2 (A), U3.6 (QG)
Col15: D70.2 (A), D80.2 (A), D81.2 (A), U3.7 (QH)
DP_CS: Dsp1.6 (CS), U1.3 (D15)
DP_DC: Dsp1.5 (DC), U1.4 (D2)
DP_RST: Dsp1.7 (RST), U1.8 (D5)
DP_SCL: Dsp1.3 (SCL), U1.9 (D18), U2.11 (SRCLK), U3.11 (SRCLK)
DP_SDA: Dsp1.4 (SDA), U1.5 (D4)
NEOPIXEL_CONTROLL: U1.10 (D19)
unnamed: D1.1 (K), SW1.2
unnamed: D2.1 (K), SW2.2
unnamed: D3.1 (K), SW3.2
unnamed: D4.1 (K), SW4.2
unnamed: D5.1 (K), SW5.2
unnamed: D6.1 (K), SW6.2
unnamed: D7.1 (K), SW7.2
unnamed: D8.1 (K), SW8.2
unnamed: D9.1 (K), SW9.2
unnamed: D10.1 (K), SW10.2
unnamed: D11.1 (K), SW11.2
unnamed: D12.1 (K), SW12.2
unnamed: D13.1 (K), SW13.2
unnamed: D14.1 (K), SW14.2
unnamed: D15.1 (K), SW15.2
unnamed: D16.1 (K), SW16.2
unnamed: D17.1 (K), SW17.2
unnamed: D18.1 (K), SW18.2
unnamed: D19.1 (K), SW19.2
unnamed: D20.1 (K), SW20.2
unnamed: D21.1 (K), SW21.2
unnamed: D22.1 (K), SW22.2
unnamed: D23.1 (K), SW23.2
unnamed: D24.1 (K), SW24.2
unnamed: D25.1 (K), SW25.2
unnamed: D26.1 (K), SW26.2
unnamed: D27.1 (K), SW27.2
unnamed: D28.1 (K), SW28.2
unnamed: D29.1 (K), SW29.2
unnamed: D30.1 (K), SW30.2
unnamed: D31.1 (K), SW31.2
unnamed: D32.1 (K), SW32.2
unnamed: D33.1 (K), SW33.2
unnamed: D34.1 (K), SW34.2
unnamed: D35.1 (K), SW35.2
unnamed: D36.1 (K), SW36.2
unnamed: D37.1 (K), SW37.2
unnamed: D38.1 (K), SW38.2
unnamed: D39.1 (K), SW39.2
unnamed: D40.1 (K), SW40.2
unnamed: D41.1 (K), SW41.2
unnamed: D42.1 (K), SW42.2
unnamed: D43.1 (K), SW43.2
unnamed: D44.1 (K), SW44.2
unnamed: D45.1 (K), SW45.2
unnamed: D46.1 (K), SW46.2
unnamed: D47.1 (K), SW47.2
unnamed: D48.1 (K), SW48.2
unnamed: D49.1 (K), SW49.2
unnamed: D50.1 (K), SW50.2
unnamed: D51.1 (K), SW51.2
unnamed: D52.1 (K), SW52.2
unnamed: D53.1 (K), SW53.2
unnamed: D54.1 (K), SW54.2
unnamed: D55.1 (K), SW55.2
unnamed: D56.1 (K), SW56.2
unnamed: D57.1 (K), SW57.2
unnamed: D58.1 (K), SW58.2
unnamed: D59.1 (K), SW59.2
unnamed: D60.1 (K), SW60.2
unnamed: D61.1 (K), SW61.2
unnamed: D62.1 (K), SW62.2
unnamed: D63.1 (K), SW63.2
unnamed: D64.1 (K), SW64.2
unnamed: D65.1 (K), SW65.2
unnamed: D66.1 (K), SW66.2
unnamed: D67.1 (K), SW67.2
unnamed: D68.1 (K), SW68.2
unnamed: D69.1 (K), SW69.2
unnamed: D70.1 (K), SW70.2
unnamed: D71.1 (K), SW71.2
unnamed: D72.1 (K), SW72.2
unnamed: D73.1 (K), SW73.2
unnamed: D74.1 (K), SW74.2
unnamed: D75.1 (K), SW75.2
unnamed: D76.1 (K), SW76.2
unnamed: D77.1 (K), SW77.2
unnamed: D78.1 (K), SW78.2
unnamed: D79.1 (K), SW79.2
unnamed: D80.1 (K), SW80.2
unnamed: D81.1 (K), SW81.2
unnamed: U2.9 (QH'), U3.14 (SER)
unnamed: U5.5 (B+), U6.2
unnamed: R10.2, U5.3 (OUT+), mcp1.1 (Vin)
unnamed: R1.1, U5.1 (ind)
POT slider Pin: U1.27 (D12), U4.4
RCLK / LATCH: R11.1, U1.28 (D13), U2.12 (RCLK), U3.12 (RCLK)
Row0: R2.1, SW1.1, SW2.1, SW3.1, SW4.1, SW5.1, SW6.1, SW7.1, SW8.1, SW9.1, SW10.1, SW11.1, SW12.1, SW13.1, SW14.1, U1.19 (D34)
Row1: R3.1, SW15.1, SW16.1, SW17.1, SW18.1, SW19.1, SW20.1, SW21.1, SW22.1, SW23.1, SW24.1, SW25.1, SW26.1, SW27.1, SW28.1, SW29.1, U1.20 (D35)
Row2: R4.1, SW30.1, SW31.1, SW32.1, SW33.1, SW34.1, SW35.1, SW36.1, SW37.1, SW38.1, SW39.1, SW40.1, SW41.1, SW42.1, SW43.1, SW44.1, U1.21 (D32)
Row3: R5.1, SW45.1, SW46.1, SW47.1, SW48.1, SW49.1, SW50.1, SW51.1, SW52.1, SW53.1, SW54.1, SW55.1, SW56.1, SW57.1, SW81.1, U1.22 (D33)
Row4: R6.1, SW58.1, SW59.1, SW60.1, SW61.1, SW62.1, SW63.1, SW64.1, SW65.1, SW66.1, SW67.1, SW68.1, SW69.1, SW70.1, U1.23 (D25)
Row5: R7.1, SW71.1, SW72.1, SW73.1, SW74.1, SW75.1, SW76.1, SW77.1, SW78.1, SW79.1, SW80.1, U1.24 (D26)
SER / DATA: U1.15 (D23), U2.14 (SER)
batt_chargesense: R1.2, R8.2, U1.26 (D14)
batt_voltage_Pin: R9.2, R10.1, U1.25 (D27)
esp32-SCL: U1.14 (D22)
esp32-SDA: U1.11 (D21)
/OE: C1.2, C2.2, C3.2, C4.2, Dsp1.2 (GND), R2.2, R3.2, R4.2, R5.2, R6.2, R7.2, R8.1, R9.1, R11.2, U1.2 (GND), U1.29 (GND), U2.8 (GND), U2.13 (~OE), U3.8 (GND), U3.13 (~OE), U4.6, U4.7 (mount), U5.2 (GND), U5.4 (OUT-), mcp1.2 (gnd)
/SRCLR: C1.1, C2.1, C3.1, C4.1, Dsp1.1 (vcc), U1.1 (3V3), U2.10 (~SRCLR), U2.16 (VCC), U3.10 (~SRCLR), U3.16 (VCC), U4.3, mcp1.3 (3.3_out)

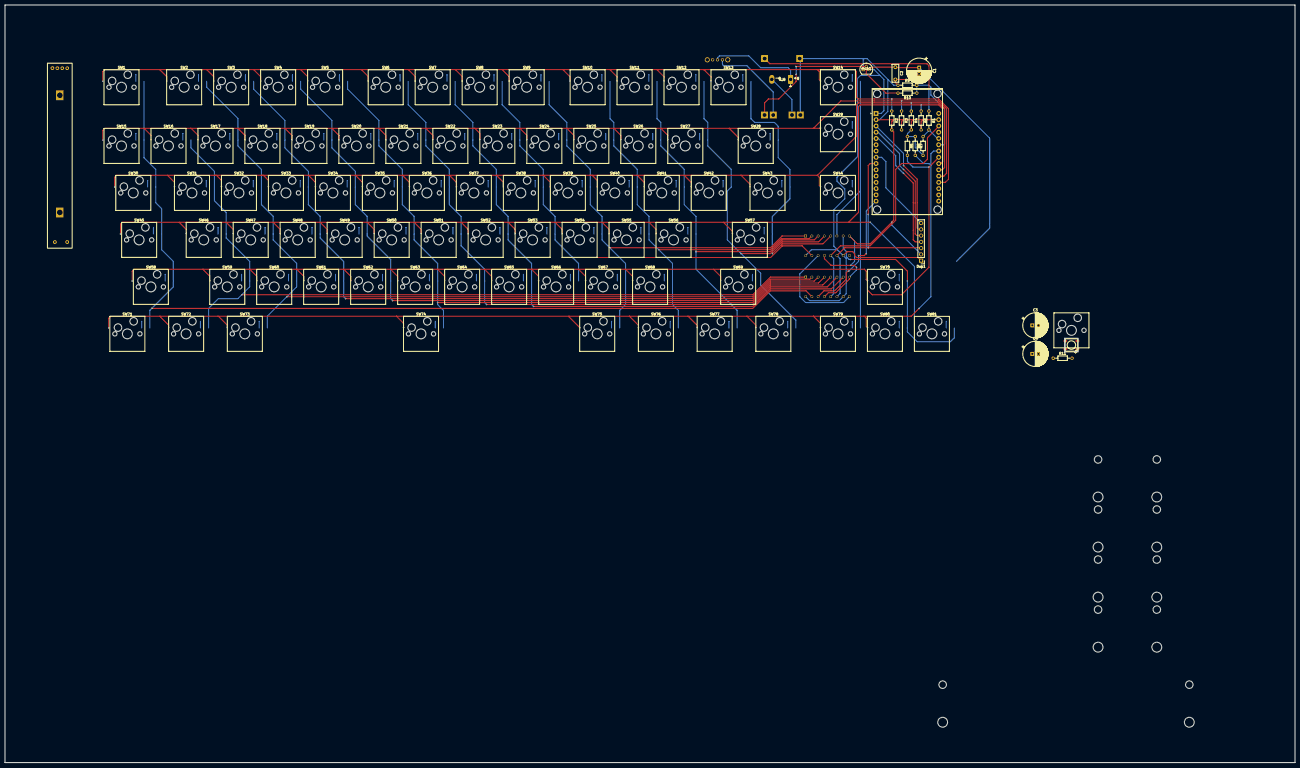
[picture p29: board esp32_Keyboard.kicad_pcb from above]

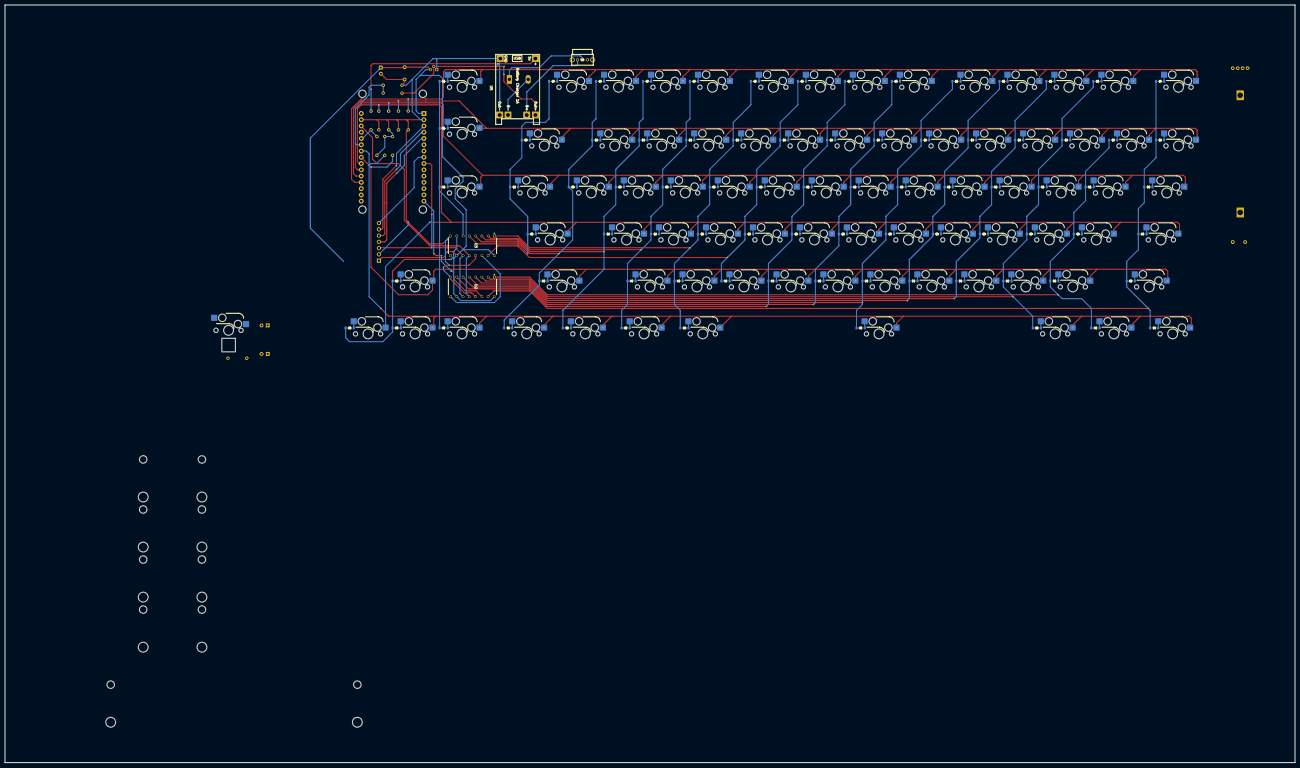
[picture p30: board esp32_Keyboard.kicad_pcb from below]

Board: 2 copper layers, 523.1 x 307.2 mm, 192 parts (85 on the bottom side), 121 nets.

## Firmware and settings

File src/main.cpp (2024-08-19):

/**
 * main.cpp
 * brief   : main compilation unit containing loop and setup
 * created : 25.05.2024
 * creator : @tigmit Licence : opensource
 */

#include "FSM.hpp"
#include "Model.hpp"
#include <Arduino.h>

#ifdef NEKO_SHELL
#include "NekoShell.hpp"
#endif

// dual core param
TaskHandle_t Loop0;       // loop running on core 0
TaskHandle_t Loop1;       // loop running on core 1 (default core)
void Loop0_(void *param); // forward declaration Loop0
void Loop1_(void *param); // forward declaration Loop1

FSM fsm; // start with default state -> pStartUp

#ifdef NEKO_SHELL
NekoShell nekoShell;
#endif

void setup() {
  Serial.begin(BAUD_RATE);

  // ----------init display
  dspHandler.init();
  // ----------init keyboard matrix
  kbdHandler.init();
  // ----------init slider Handler
  sliderHandler.init();
  // ----------init battery handler
  batHandler.init();
  // ----------init RGB handler
  rgbHandler.init();
  // ----------init Rotary Encoder
  encHandler.init();
#ifdef NEKO_SHELL
  // ----------init NEKO SHELL
  nekoShell.init();
#endif

  // creating loop on core 1 (default core)
  xTaskCreatePinnedToCore(Loop0_, "Loop0", 10000, NULL, 0, &Loop0, 0);
  // creating loop on core 0 with prio 1
  xTaskCreatePinnedToCore(Loop1_, "Loop1", 10000, NULL, 1, &Loop1, 1);
}

void Loop0_(void *param) {
  // setup section for loop0:

  //__________________RUN Loop0
  while (true) {
    fsm.update(); // running statemachine
  }
}

void Loop1_(void *param) { // explicitly for scanning the key matrix
  // setup section for loop1:
  //__________________RUN Loop1 (default core)
  while (true) {
    kbdHandler.updateKeyMatrix();
  }
}

// nothing to do here
void loop() {}

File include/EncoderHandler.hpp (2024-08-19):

/**
 * ../lib/EncoderHandler.hpp
 * brief   : this class handles all the tasks required to read the rotary
 * encoder created : 25.05.2024 creator : @tigmit Licence : opensource
 */
#pragma once

#include <Arduino.h>
#include <ESP32Encoder.h> // https://github.com/madhephaestus/ESP32Encoder.git
#include <math.h>

class EncoderHandler {
public:
  EncoderHandler() = default;

  void init() {
    encoder.attachHalfQuad(encDT, encCLK);
    encoder.setCount(0);
    pinMode(encBTN, INPUT);
  }

  void UpdateMainStateSelect(int &modeSet, u_int8_t numStates) {

    // checking encoder val state
    encoderPosition = encoder.getCount() / 2;
    if (encoderPosition == 0) {
      // do nothing
    } else if (encoderPosition > 0) {
      modeSet++;
      modeSet %= numStates;
      encoder.clearCount();

    } else if (encoderPosition < 0) {
      modeSet = (modeSet == 0) ? numStates - 1 : modeSet - 1;
      encoder.clearCount();
    }
  }

  void UpdateRgbStateSelect(int &modeSet, u_int8_t numStates) {

    // checking encoder val state
    encoderPosition = encoder.getCount() / 2;
    if (encoderPosition == 0) {
      // do nothing
    } else if (encoderPosition > 0) {
      modeSet++;
      modeSet %= numStates;
      encoder.clearCount();

    } else if (encoderPosition < 0) {
      modeSet = (modeSet == 0) ? numStates - 1 : modeSet - 1;
      encoder.clearCount();
    }
  }

  bool UpdateColorPickerSelect(uint8_t &modeSet) {

    // checking encoder val state
    encoderPosition = encoder.getCount() / 2;
    if (encoderPosition == 0) {
      // do nothing
    } else if (encoderPosition > 0) {
      modeSet += colorPickerIncrement;
      modeSet %= 255;
      encoder.clearCount();
      return true;

    } else if (encoderPosition < 0) {
      modeSet -= colorPickerIncrement;
      modeSet = (modeSet < 0) ? 0 : modeSet % 255;
      encoder.clearCount();
      return true;
    }
    return false;
  }

  bool updateRgbBrightnessSelect(uint8_t &brightness,
                                 uint8_t maxBrightness = 0x1E) {
    // checking encoder val state
    encoderPosition = encoder.getCount() / 2;
    if (encoderPosition == 0) {
      // do nothing
    } else if (encoderPosition > 0) {
      brightness += brightnessIncrement;
      brightness = (brightness >= maxBrightness) ? maxBrightness : brightness;
      encoder.clearCount();
      return true;

    } else if (encoderPosition < 0) {
      int buff = brightness;
      buff -= brightnessIncrement;
      brightness = (buff <= 0) ? 0 : buff;
      encoder.clearCount();
      return true;
    }
    return false;
  }

  void UpdateRgbAcceptSelect(int &modeSet) {

    // checking encoder val state
    encoderPosition = encoder.getCount() / 2;
    if (encoderPosition == 0) {
      // do nothing
    } else if (encoderPosition > 0) {
      modeSet = 1;
      encoder.clearCount();
    } else if (encoderPosition < 0) {
      modeSet = 0;
      encoder.clearCount();
    }
  }

  bool EncButtonPressed() {
    // check if the button was pressed
    int reading = digitalRead(encBTN);

    if (reading != lastButtonState) {
      lastDebounceTime = millis();
    }

    if ((millis() - lastDebounceTime) > debounceDelay) {
      if (reading != buttonState) {
        buttonState = reading;
        if (buttonState == LOW) {
          return true;
        }
      }
    }
    lastButtonState = reading;
    return false;
  }

  void updateVolume() {
    int8_t VolPosition = encoder.getCount() / 2;
    if (VolPosition > 0) {
      kbd.write(KEY_MEDIA_VOLUME_UP);
      encoder.clearCount();
    } else if (VolPosition < 0) {
      kbd.write(KEY_MEDIA_VOLUME_DOWN);
      encoder.clearCount();
    }
  }

private:
  ESP32Encoder encoder;

  long encoderPosition = 0;
  uint8_t colorPickerIncrement = 5;
  uint8_t brightnessIncrement = 1;

  int buttonState;
  int lastButtonState = HIGH;

  unsigned long lastDebounceTime = 0;
  unsigned long debounceDelay = 50;
};

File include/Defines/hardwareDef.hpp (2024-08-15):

/**
 * hardwareDef.hpp
 * brief   : defining the pins for the key matrix
 * created : 25.05.2024
 * creator : @tigmit
 * Licence : opensource
 */
#pragma once
#include <Arduino.h>

// baud rate
static constexpr unsigned long BAUD_RATE{115200};

// Define on and off values
static constexpr uint8_t OFF{0};
static constexpr uint8_t ON{1};

// Pin Definitions
static constexpr int row0{34}; // TODO: gotta set these accoarding to schematics
static constexpr int row1{35};
static constexpr int row2{32};
static constexpr int row3{33};
static constexpr int row4{25};
static constexpr int row5{26};

// Analog Slider
static constexpr int SliderReadPin{12};

// battery is charging indicator
static constexpr int BatterySense{14};

// reading the battery voltage through 33k / 100k voltage devider
static constexpr int BatteryVoltage{27};

// Matrix setup
static constexpr int numRows{6};
static constexpr int numCols{15};
static constexpr int numLayers{1};

// i2C adress for display ESP32
static constexpr int SlaveEspAdress{9};

// pins for rotary Encoder
static constexpr int encCLK{17}; // CLK ENCODER
static constexpr int encDT{16};  // DT ENCODER
static constexpr int encBTN{39}; // encoder button

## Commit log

2024-05-26 add framework for GC9A01 Display
2024-05-28 create keyboard layout
    [SN74HC595NG4.step, esp32_Keyboard.kicad_pcb, esp32_Keyboard.kicad_sch]
2024-05-28 finished layout circuit baord V1
    [esp32_Keyboard.kicad_pcb, esp32_Keyboard.kicad_sch]
2024-05-29 current status not tested. waiting for hardware PCB
2024-05-29 finished PCB design
    [bom.csv, designators.csv, esp32_Keyboard.kicad_pcb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]
2024-06-19 add spi lib to gitignore
2024-06-19 kicad stuff
2024-06-19 display lib compiling state
    [esp32_Keyboard.kicad_sch]
2024-06-19 commit current work
    [esp32_Keyboard.kicad_pcb, esp32_Keyboard.kicad_sch]
2024-06-19 working state with new wallpaper
    [esp32_Keyboard.kicad_sch]
2024-06-19 added ecoder and LED Support
    [esp32_Keyboard.kicad_pcb, esp32_Keyboard.kicad_sch]
2024-06-26 saving kicad progress HW rev2
    [PowerDeliveryBoard.kicad_pcb, PowerDeliveryBoard.kicad_sch, esp32_Keyboard.kicad_sch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]
2024-07-06 working version for tigmit board rev1 release candidate
    [PowerDeliveryBoard.step, bom.csv, designators.csv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]
2024-07-21 hardware design updates
    [1_Case_Bottom.stl, 1_keyplate.stl, 2_Case_Bottom.stl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]
2024-07-28 menu working + LED Screen immage
2024-08-02 create all 3d Case files for order rev V1 compatible with pcb Rev2
    [1_Case_Bottom.stl, 1_keyplate.stl, 2_Case_Bottom.stl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]
2024-08-02 ontrocuduce documentation and readme
    [TKL_Cherry_Only_Keyplate.dxf]
2024-08-02 forgott to close kicad
2024-08-03 move espi lib locally to avoid losing user settings
    [BatteryHandler.hpp, DisplayHandler.hpp, EncoderHandler.hpp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]
